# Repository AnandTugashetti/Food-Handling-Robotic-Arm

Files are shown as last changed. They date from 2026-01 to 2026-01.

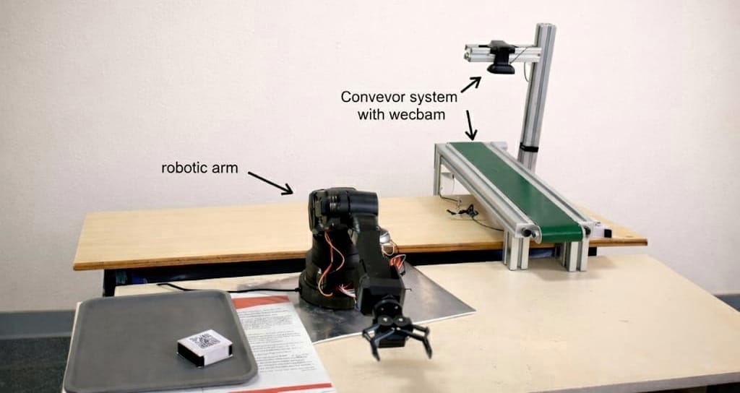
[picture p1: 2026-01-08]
Full_setup_Model.jpeg

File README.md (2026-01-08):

🍽️ Food Handling Robotic Arm

An automated robotic system designed to handle packed food items safely and efficiently using a robotic arm, conveyor belt, and QR-code–based identification.

📌 Project Overview

The Food Handling Robotic Arm project aims to improve hygiene, accuracy, and speed in food handling by reducing human involvement. The system uses a robotic arm integrated with a conveyor belt and a camera-based QR scanning mechanism to automatically pick, sort, and place packed food items to their respective destinations.

This solution is suitable for small to medium-scale food industries and Quick Service Restaurants (QSRs) where fast and reliable order handling is essential.

⚙️ System Features

Automated pick-and-place operation

QR code–based food package identification

Conveyor belt coordination

Servo motor–controlled robotic arm

Minimal human intervention

Modular and scalable design

🧠 System Workflow

Food package moves on the conveyor belt

Webcam scans the QR code on the package

Order or customer information is decoded

Decision is made for destination placement

Robotic arm picks the package

Package is placed at the assigned location

🧾 Project Report

File: Food_Handling_Robotic_Arm_Report.pdf

Contents Include:

Introduction and objectives

Literature survey

System design and development

Hardware and software implementation

Testing, results, and discussion

Conclusion and future scope

🧩 Autodesk Fusion 360 – Robotic Arm Design

File Name: Food_Handling_Roboticarm_Design

Software Used: Autodesk Fusion 360

The robotic arm used in this project was designed and modeled using Autodesk Fusion 360. The software was selected for its powerful parametric modeling tools, easy assembly management, and accurate visualization capabilities, which are well suited for robotic system design.

The complete robotic arm design includes:

Base structure

Shoulder, elbow, and wrist joints

End-effector (mechanical gripper)

Servo motor mounting brackets

Linkages and joint connections

Each component was modeled individually and then assembled to ensure proper alignment, range of motion, and mechanical stability. Joint constraints and motion limits were applied to simulate real-world arm movements and to verify reachability and workspace.

🌐 Roboslice – Food Ordering Web Application

Application Name: Roboslice

Live Link: https://roboslice.onrender.com/

Type: Web-based food ordering system

Roboslice is a web application developed to manage food orders digitally and integrate seamlessly with the automated food handling system. It allows customers to place orders easily and generates a unique QR code for each order, which is later used by the robotic arm system for identification and sorting.

📝 Order Creation Process

Using the Roboslice web application, the user can place an order by providing the following details:

Food item selection

Customer name

Quantity of items

Order type (Dine-in or Takeaway)

Payment confirmation

Once all required inputs are submitted, the system automatically generates a unique QR code for the order.

🔲 QR Code Generation

Each order is assigned a unique QR code

The QR code contains essential order and customer information

This QR code is printed or attached to the food package or bill

The generated QR code is later scanned by the webcam-based QR scanner

This QR code acts as a digital link between the web application and the robotic arm system, enabling automated decision-making.

🔗 Integration with Robotic Arm System

The webcam scanner reads the QR code generated by Roboslice

Order data is decoded and processed

The system identifies the correct customer or destination

The robotic arm performs accurate pick-and-place operations

This integration ensures faster order handling, reduced errors, and minimal human involvement.

🤖 Robotic Arm Control Code

Folder: Robotic_arm_arduino_code

Software Required: Arduino IDE

Purpose:
Controls servo motors, robotic arm movement, and pick-and-place operations.

▶️ How to Run

Open Arduino IDE

Open the .ino file from : Robotic_arm_arduino_code

Select the correct Board and COM Port

Upload the code to the Arduino

📷 Webcam QR Scanner Code

Folder: webcam_scanner_code

Software Required: Visual Studio Code (VS Code)

Purpose:
Scans QR codes using a webcam to identify orders and trigger customer-related actions.

▶️ How to Run

Open VS Code

Open the : webcam_scanner_code folder

Install required Python libraries:

pip install opencv-python pyzbar

Run the scanner script

🧪 Testing Summary
End-to-end automation successfully demonstrated

Reliable QR detection under proper lighting

Effective handling of 150–300 g food packets

Average cycle time: ~30 seconds per order

🚀 Future Enhancements

Adaptive or soft robotic grippers

Vision-based alignment correction

IoT integration for order tracking

Cloud-based monitoring and analytics

Industry 4.0–ready automation

📜 License

This project is intended for academic and educational use.

Feel free to fork, modify, and improve the system.

👤 Author

Anand Tugashetti

Robotics & Automation

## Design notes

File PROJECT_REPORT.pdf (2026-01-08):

A PROJECT REPORT ON

## FOOD HANDLING ROBOTIC ARM

ANAND TUGASHETTI
2025-2026

ABSTRACT

Automation tends to become a key enabler in modern food industries, enhancing hygiene,

efficiency, and accuracy while reducing dependence on manpower. Challenges faced in

conventional food handling practices include contamination risks, inconsistent handling

quality, slower processing speed, and higher labour costs. The main goal of this project is thus

to design and develop a Food Handling Robotic Arm, an automated system that would safely

and efficiently handle packed food items with minimal human involvement.

The fundamental idea of the project is to design an automated mechanism which can pick,

place, and sort packed food items arriving from a kitchen and deliver them to the correct

customer or the respective section. The robotic arm-based system with a conveyor belt, camera-

based identification, sensors, servo motors, and a microcontroller-based control unit provides

a complete automated solution. A food package traveling on the conveyor may have a QR code

or barcode printed on the package or order bill, which is detected and scanned by a camera.

The scanned data is processed through a microcontroller that decides to which destination it

should go based on the information regarding customers or delivery. Based on this decision,

the robotic arm executes a pick-and-place operation with high precision.

It works on the principle of continuity and repetition. Once a package is detected, the robotic

arm is guided to the pickup point, where a soft, food-grade gripper gently grips the package to

avoid damage. The arm then transfers and places the item accurately at the assigned location.

This operation will be looped so that the system can handle multiple orders of food efficiently

with high speed and reliability.

The advantages of the Food Handling Robotic Arm include better hygiene with less human

contact, consistent accuracy of handling, and speedier ways of processing orders. Its design is

modular and adaptable, fitting into small kitchens and large-scale food industries. This system

shall be very useful in QSRs like Domino's, Burger King, McDonald's, and KFC since these

need quicker service due to high order volumes. Overall, the project showcases a highly

feasible automation solution aimed at enhancing operational efficiency, hygiene, and customer

satisfaction, while also opening up future possibilities of IoT and Industry 4.0 integration.

TABLE OF CONTENTS

2.28 Design and Control of Soft-Rigid Grippers for Food Handling | 29
2.29 Review of Robotic Grippers for High-Speed Handling of Fragile Foods | 29

2.30 Design and Field Evaluation of End Effector for Robotic Strawberry Harvesting...30

Chapter 3: Problem Statement | 32
Chapter 4: Objectives | 33
Chapter 5: Design & Development | 34
5.1 Overview | 34
5.2 System Design & Mechanical Design | 35
5.3 Development Framework for the Robotic Food Handling System... | 37
5.4 Workflow Diagram of Automated Food Handling System | 38
Chapter 6: Implementation | 39
6.1 Hardware Implementation | 40
6.2 Software Implementation | 48
6.3 Servo Motor Control Connections | 40
6.4 Roboslice – Web Application | 50
Chapter 7: Validation & Testing | 52
7.1 Validation Objectives | 52
7.2 Testing Setup | 53
7.3 Full System Integration Testing | 54
Chapter 8: Results & Discussion | 57
Conclusion | 59
Future Scope | 60
References | 61
Plagiarism check report | 63

LIST OF TABLE

Sl.No | Description | Page No.
Table 7.1 | End-to-End Cycle Success Rate | 55

LIST OF FIGURES

Sl.No | Description | Page No.
Fig 5.1 | Block Diagram | 34
Fig 5.2 | Workflow Diagram | 39
Fig 6.1 | Circuit Diagram | 40
Fig 6.2 | Arduino Uno | 41
Fig 6.3 | MG995 Servo Motor | 42
Fig 6.4 | SG90 Servo Motor | 43
Fig 6.5 | Conveyor System | 43
Fig 6.6 | Webcam | 44
Fig 6.7 | Lithium Battery | 45
Fig 6.8 | 3D Printing Filament | 46
Fig 6.9 | Breadboard | 46
Fig 6.10 | Adapter | 47
Fig 6.11 | Jumper Wires | 47
Fig 6.12 | Geared DC Motor | 48
Fig 6.13 | 3D Model of Robotic Arm | 49
Fig 7.1 | Robotic Arm | 55
Fig 7.2 | Mechanical Gripper | 55
Fig 7.3 | Conveyor | 55
Fig 7.4 | Robotic Arm Components | 55
Fig 7.5 | Testing Of Robotic Arm | 56
Fig 8.1 | Complete Working Model | 58

## CHAPTER 1

## INTRODUCTION

With kitchens getting smarter and food moving quicker, the quiet revolution shaping their

future is not culinary, but robotic. The rapid growth of automation during the 21st century has

evidently restructured industries across the world and considerably influenced how products

are created, processed, packed, and delivered. Of all sectors undergoing transformation, the

food industry stands out as one of the most demanding, complex, and sensitive domains to

integrate technology. Food is not just another commodity-it is essential for life and hence

requires handling with high standards of hygiene, precision, safety, and efficiency.

### 1.1 Introduction to Robotic Automation in Modern Food Handling

In recent years, the rise of quick-service restaurants, cloud kitchens, large commercial food

outlets, and online delivery platforms worldwide has amplified the challenge of managing huge

volumes of food items with speed and accuracy. Given this backdrop, robotic automation is

emerging as a promise that can handle not only operational inefficiency but also hygiene-

related issues. The development of a food-handling robotic arm addresses these growing

industrial needs and thus presents a pathway to enhancing efficiency, improving safety, and

raising the overall standard for performing food handling.

The modern food consumer expects speedy delivery, accuracy, and safety. When ordering

through an online platform or dining in-store, delays, mistakes, or unsafe handling will badly

affect customer confidence. Traditional food-handling environments rely heavily on human

labor. While humans are endowed with dexterity, adaptability, and decision-making ability,

they are also susceptible to fatigue, inconsistency, errors, and limitations during peak demand

periods. In a busy kitchen or zone of food dispatch, workers tend to perform repetitive tasks

like sorting packaged meals, checking order labels, routing trays to different sections, and

organizing prepared plates for serving or dispatch. These simple-appearing tasks require

uninterrupted concentration and physical stamina. Over some time, the monotony of such tasks

leads to degraded accuracy, slower performance, and bottlenecks in operation. Further, direct

human contact in handling food increases the chances of contamination, highlighted throughout

the COVID-19 pandemic.

Automation presents an alternative to this system because it guarantees precision, consistency,

and operation without interruption. A food-handling robotic arm designed for executing repetitive tasks at very high speeds with high accuracy can operate around the clock and

drastically minimize the chances of cross-contamination. Equipping it further with an

intelligent system such as barcode or QR-code scanning allows the direct identification,

sorting, and routing of packaged items automatically without human oversight. So instead of

reading labels, workers could take advantage of the robot's interpretation of data instantly and

move items to their allocated places. This combination of robotics and machine perception

transforms the work from labor- to data-driven with exceptional efficiency.

### 1.2 Challenges, Technological Enhancements, and Industrial Relevance

The idea of using robotic arms in industry is not new; the so-called robotic manipulators have

been in use in manufacturing, automotive assembly, pharmaceuticals, and production of

electronics. However, the food industry presents some unique challenges that significantly

differ from the requirements of traditional industrial automation. Foodstuffs differ in shape,

texture, and fragility, along with several different packaging styles. While a metal component

on an assembly line may not be affected when handled with firm gripping or fast-moving

motions, a packaged food item or a soft edible product might deform, create spills, or otherwise

be damaged if subjected to excessive force or an incorrectly designed gripping mechanism.

This, however, has fueled the development of food-safe gripping technologies, including soft

robotic grippers, vacuum-based grippers, and an adaptive mechanism capable of modifying

grip pressure depending on the character of an object. Such advances now make it possible for

robotic arms to handle delicate or irregularly-shaped food items with high-quality manipulation

close to that of human hands.

Apart from gripping technology, the integration of machine vision is what allows robotic arms

to intelligently interact with the environment in which they exist. QR codes and barcodes are

now universal ways of embedding information regarding order numbers, customer IDs,

packing timestamps, temperature, and routing information. This information, through camera-

based scanning systems, can be decoded in real-time as a robotic arm views it and carries out

decisions on placement and sorting. This removes dependency on manual verification and

reduces logistical errors. When integrated into conveyor systems or modular food dispatch

environments, such robotics technology creates a seamless flow where each food item moves

through a digital pipeline from preparation to dispatch.

The need for such automation has been further intensified due to the changing structure of food

distribution systems. Cloud kitchens—places specifically dedicated to preparing online food

orders without dine-in facilities—are enjoying increasing popularity, meaning the number of orders daily could be very high. Cloud kitchens rely heavily on optimized workflows to

maintain profitability. A single delay in sorting or routing food containers can create order

bottlenecks, extend delivery times, and reduce efficiency. As multiple brands operate under

one kitchen roof, simultaneous orders become all the more complex to handle. Robotic arms

are capable of performing such tasks in large volumes with consistency and accuracy, thus

providing a standardized solution to these challenges. They can manage everything, from

picking boxed meals from a conveyor and scanning their QR labels to depositing them into

assigned racks for delivery partners, without fatigue or error.

Beyond efficiency and hygiene, robotic automation supports broader industrial goals in line

with the principles of Industry 4.0. This new wave of industrial transformation emphasizes

interconnected systems, data-driven decision-making, real-time monitoring, and intelligent

automation. A food-handling robotic arm can be easily integrated with IoT devices, kitchen

management software, cloud-based analytics, and automated dispatch systems. Every food

packet handled by the robot can be digitally logged, making traceability transparent and

accurate. Processing times can be monitored, the busiest hours can be identified, workflow

bottlenecks can be predicted, and staffing can be optimized based on data insights. Because the

robotic system records every movement, it provides unprecedented visibility into the food-

handling pipeline, offering opportunities for continuous improvement.

Furthermore, advances in technology have made robotic systems more available and

affordable. While previously robotic automation was made possible only in large factories with

big budgets, today it has become accessible to even small- and medium-scale food businesses

due to modular actuators, low-cost microcontrollers, 3D-printed parts, and opensource robotic

frameworks. Today, a multi-degree-of-freedom robotic arm can be realized at a fraction of its

earlier cost while maintaining high reliability. The integration of opensource libraries for QR-

code recognition, microcontroller-based control systems, and low-cost camera modules will

make the technology practical and scalable. As robotics becomes more affordable, its potential

to revolutionize the food industry expands further.

In view of these considerations, the development of a food-handling robotic arm is not an

academic exercise; it is to find a solution for practical industrial problems. This project tries to

fill the gap between practical kitchen operations and future automatic food handling. Hence, it

handles some major challenges like sorting errors, hygiene risks, labor shortcomings, and

inefficiency in operations. Combining robotic manipulation with computer vision, the system

shows how technology can improve quality and speed in food handling.

## CHAPTER 2

## LITERATURE SURVEY

The literature survey reviews the existing research on robotic automation in food handling,

including discussions related to pick-and-place systems, vision-based identification, conveyor-

integrated robots, and food-safe gripper designs. Previous work underlines the role of robotic

arms in enhancing hygiene, accuracy, and efficiency in food processing applications. The

survey also identifies the need for integrated, cost-effective solutions combining sensing,

control, and automation specifically for modern food handling applications.

### 2.1 Robotic Manipulation of Food Products

Author: P.Y. Chua, T. Ilschner, D.G. Caldwell

This paper provides in-depth discussion on the advances, challenges, and opportunities of

applying robotic systems to food handling and processing. Although the food industry is among

the largest manufacturing sectors in the world, its automation is lagging behind the automotive

and electronic industries. This is mostly because food products are variable, soft, and easily

deformed, hence difficult to handle by conventional robotic manipulators. The authors stressed

that automation in this sector is very important for enhancing hygiene, efficiency, and

profitability without compromising on strict food safety regulations.

The paper identifies the core problems of robotic food manipulation in terms of product size

and texture variations, which are easily deformed or contaminated, and which require a truly

cleanable robot. Three of the major strategies for gripping are discussed in more detail.

Mechanical grippers achieve their hold through friction or clamping and can be used on

products like meat or fish. Fragile produce is at risk with this type of gripper. Intrusive grippers

pierce through a material and cannot be considered due to hygiene implications. Surface

attraction grippers, which involve suction, adhesives, or electrostatic forces, offer greater

adaptability but tend to get clogged or contaminated easily. New approaches involve ideas like

freezing grippers by using rapid ice adhesion and airflow-based noncontact grippers.

The authors illustrate several practical robotic applications, including food processing and

manufacture. Washable manipulators execute cutting and dressing operations in meat

processing with high accuracies and hygiene standards. The grippers of poultry-handling robots

use pneumatic muscles to avoid damages on their fragile tissues. SCARA robots automatically

de-head fish on the "RoboFish" project, while sensors and pneumatics enable the robotic milking systems to milk cows accurately and independently. Agricultural robots execute

selective harvesting on asparagus, fruits, and mushrooms where vision systems and soft

grippers are integrated into the robotic apparatus. Automation of packaging, examples include

ABB's FlexPicker and Intelligent Integrated Belt Manipulator, presents the most successful

area of food robotics due to standardized material and shape inputs.

### 2.2 Kinematic Modelling & Maneuvering of 5-Axes Articulated Robot Arm

Author : T.C. Manjunath

This paper presents the complete design, mathematical modeling, simulation, and real-world

implementation of a 5-DOF articulated robotic arm developed totally from indigenous

components. The paper focuses on the derivation of an accurate direct kinematic model for the

manipulator using the D–H convention and further validates the model through simulation and

actual pick-and-place experiments. The robot has five rotary joints (base, shoulder, elbow,

pitch, and roll), and is designed as an educational platform for teaching robotic manipulation.

It is powered by DC servomotors through gear–chain transmission systems and incremental

encoders with a resolution of 0.624° per count at the load shaft. The manipulator is therefore

able to execute high-precision joint motions. The D–H based modeling process involves the

assignment of six coordinate frames, the derivation of 20 kinematic parameters, and the

computation of the sequence of homogeneous transformation matrices from the base to the

tool-tip. These matrices are partitioned at the wrist to simplify computation, thereby allowing

the computation of end-effector position and orientation relative to the base. One complete

composite transformation matrix T₅⁰ is formulated and validated by substituting the soft-home

joint angles of the robot.

The author then develops a detailed link coordinate diagram or LCD, computes joint variables,

link lengths, offsets, and twist angles, and constructs a full kinematic parameter table. The

correctness of the derived matrices is verified by evaluating the transformation matrices at the

home position and cross-checking with the LCD.

A C++-based GUI is developed to realize real-time simulation and control of the robot.

MATLAB simulations performed show consistency with the experimental results in pursuing

accurate trajectory tracking and successful autonomous pick-and-place manipulation.

Concluding, the paper develops a comprehensive kinematic approach and its practical

implementation for a 5-axis robotic arm, with a particular emphasis on its application as an

affordable platform for teaching robot kinematics and manipulation in educational and research

settings.

### 2.3 Low-Cost Compliant 7-DOF Robotic Manipulator

Author : Morgan Quigley, Alan Asbeck, and Andrew Y. Ng

The paper presents the design and implementation of an affordable, human-safe robotic arm

that is intended for manipulation research. Unlike the commercial manipulators that often

exceed $100,000, this system achieves backlash-free actuation, sub-3 mm repeatability, 1.5

m/s speed, and a 2 kg payload at the low parts cost of $4135. The motivation behind this project

was to accelerate robotics research by making high-performance arms financially accessible,

enabling their wider adoption in labs, classrooms, and small-scale industries.

The key innovation of the arm is its hybrid actuation mechanism. The proximal four joints

utilize stepper motors with timing belts and cable drives, providing features like high torque,

zero backlash, and intrinsic mechanical compliance. This series-elastic design increases human

safety because external forces applied to the arm cause it to safely deflect. The distal three

joints employ Dynamixel RX-64 servos that enable higher bandwidth motion while allowing

overall flexibility.

Low-cost manufacturing is achieved with laser-cut plywood and off-the-shelf components,

with no expensive machining. The compliance mechanism makes use of polyurethane tubes

deforming under force; thus, accurate force sensing is achieved through encoder measurements.

Equipped with the full sensing stack—optical encoders, motor step tracking, and ROS-based

software integration—the arm features closed-loop control, inverse kinematics, and Cartesian

motion planning.

Performance tests demonstrate excellent repeatability and payload handling, whereas

demonstration tasks such as teleoperated chess-playing and pancake-making highlight the

arm's capability for fine manipulation and safe human interaction.

The authors conclude that this low-cost, compliant 7-DOF arm represents an important step

toward affordable, safe manipulation systems. Future work will involve simplifying

fabrication, improving force sensing, and moving toward more durable metal structures to

make compliant robots practical for widespread deployment.

### 2.4 Unified Closed Form Inverse Kinematics for the KUKA YouBot

Author : Shashank Sharma, Gerhard K. Kraetzschmar, Christian Scheurer, and Rainer

Bischoff

This paper proposes a new analytical inverse kinematics solution for the KUKA youBot mobile

manipulator by considering it as a unified 8-DOF serial kinematic chain, where the base and

5-DOF arm are included. The authors fill a key gap in the literature on mobile manipulation:

although mobile platforms introduce redundancy that should enhance reachability and

flexibility, most systems operate the base independently of the arm and rely on heuristic-based

planning. In this paper, the authors propose a unified closed-form IK solver able to

systematically exploit redundancy, thus enabling more efficient and deterministic manipulation

in complex environments.

The paper initiates by explaining the difficulties of mobile manipulation, especially the

coordination of base motion and arm articulation for accomplishing 6D end-effector goals.

Since the youBot's arm has only 5 degrees of freedom, the missing DOF must be compensated

by platform movement. The authors introduce three redundancy parameters (ρ1, ρ2, ρ3): ρ1

resolves rotational redundancy between base and first joint, ρ2 adjusts linear redundancy linked

to arm reach, and ρ3 determines elbow configuration (up or down).

A systematic, analytical IK framework is developed. The solver first extracts orientation

parameters β and θ from the Cartesian goal pose and then computes the arm joint angles (θ2,

θ3, θ4), based on geometrical and trigonometric relationships. In order to satisfy the overall 6D

goal pose, the position (x, y) of the mobile base and the orientation will be derived, while θ5 is

computed from the rotational alignment between the current and desired end-effector frames.

The valid range of redundancy for the solver is also defined based on mechanical constraints.

Simulation and experimental results demonstrate smooth joint trajectories for redundancy

parameter updates confirming independence and allowing true nullspace motion. The unified

solver enables efficient manipulation planning using IKBiRRT without heuristic base

sampling.

They conclude that this unified closed-form IK solution significantly advances mobile

manipulation since it allows the youBot to fully exploit its redundancy and perform more

robustly and efficiently in complex tasks.

### 2.5 An Evaluation System of Robotic End-Effectors for Food Handling

Author: Zhe Qiu, Hannibal Paul, Zhongkui Wang, Shinichi Hirai, Sadao Kawamura.

The paper presents a holistic framework for the assessment of robotic end-effectors in

performing manipulation tasks related to food handling. The motivation has come from

growing demands on automation within Japan's food industries, which have been driven by

labor shortages and the complexity of handling a wide variety of food stuffs. Most of the

already-developed robotic end-effectors are designed for specific types of food; hence, their

generalization is limited. In this work, an attempt has been made to propose an evaluation

system that can quantitatively and graphically visualize the performances of various end-effectors in manipulating different food materials, with the objective of aiding in the selection

or new design of end-effectors.

The authors classify the food items and the robotic end-effectors according to their physical

and functional characteristics. Food products are categorized according to such body properties

as shape, size, weight, elasticity, and fragility, while surface properties include friction,

stickiness, humidity, and temperature. These parameters directly affect the grasping success

and product safety. On the other hand, robotic end-effectors are classified according to their

contact position during handling in top, side, and bottom configurations-in other words, T-type,

S-type, B-type, or hybrid configurations, like TS, BS, and TBS types. Such a classification

enables structured performance comparisons among several device designs. The evaluation

framework consists of a robotic system based on the ROS 2 platform, equipped with a Denso

robotic arm, pneumatic controllers, and an Intel RealSense 3D camera for visual recognition.

The methodology included standardized pick-and-place experiments on 14 different food items

using seven soft robotic end-effectors. Each end-effector's adaptability is rated across seven

properties: shape, size, weight, friction, elasticity, stickiness, and fragility. Performance scores

are visualized using radar charts, which provide an intuitive representation of overall efficiency

and capability.

Experimental results indicated that no single end-effector operates optimally for all types of

food. For example, suction-based grippers operate well on smooth surfaces but failed when the

item was sticky or had a coarse surface. Pneumatic and soft-finger grippers displayed greater

adaptability, especially when it came to fragile or oddly-shaped foods. Radar-based

visualization of scoring offered insight into design limitations and provided direction for end-

effector optimization.

### 2.6 Vision Assisted Pick and Place Robotic Arm

Author : Nisha, Dinesh Kumar, Sekar, and Indira

The paper describes the design and implementation of a 2-DOF robotic arm integrated with a

machine vision system that is capable of fully automated pick-and-place operations. This

system differs from traditional manually guided robotic arms in such a way that it utilizes a

USB camera as a vision sensor and incorporates LabVIEW Machine Vision (NI-IMAQ) for

capturing live images and processing. The primary objective remains to identify an object

autonomously, measure its dimensions, and precisely guide the robot to pick and relocate it

without human interference.

The robotic arm is fabricated from lightweight acrylic sheets and actuated by three servo

motors: one each for the base, wrist, and gripper. The base rotates the entire arm, the wrist

provides vertical motion, and the gripper, through a servo-driven wheel mechanism, is able to

grasp widths from 1.0 to 9.3 cm. It has a total mass of 500 g and is 19 cm tall, and therefore is

cost-effective, portable, and suitable for small-scale automation.

The vision system captures object images and performs image processing based on RGB-to-

grayscale conversion, pattern matching, and edge detection algorithms. Pattern matching finds

template similarity and extracts pixel coordinates while edge detection, with the Prewitt

operator, computes the dimensions of objects. Pixel values are converted to real-world units

using a calibration constant 1 pixel = 0.026458 cm. These measurements are then sent to the

servo motors via RS-232 communication using an LPC2129 ARM7 microcontroller

programmed to produce the appropriate PWM signal that drives the servos.

Experimental tests demonstrate the system reliably detects object dimensions, while slight

discrepancies exist due to camera resolution and other illumination factors. The authors identify

that the integration of vision significantly improves the automation capability, but full-scale

industrial applications will involve increasing DOF up to at least seven and employing higher-

resolution 3D cameras in order to achieve more accurate sensing.

### 2.7 Design and Implementation of Pick and Place Robotic Arm

Author : Ravikumar Mourya, Amit Shelke, Sourabh Satpute, Sushant Kakade, Manoj Botre

The paper describes the complete mechanical, control, and analytical development of a 4-DOF

articulated pick-and-place robotic arm for cylindrical objects weighing up to 150 grams. The

objective of the study was to replace human intervention in repetitive material-handling tasks

and to present a lightweight, low-cost, and efficient robotic solution for industrial

environments.

The authors first present the necessity for robotic manipulators and emphasize their role in

hazardous, repetitive, or precision-demanding tasks. The robotic arm described here uses a

model based on the human upper limb, having four revolute joints with each joint actuated by

a servo motor. This, in turn, provides four degrees of freedom: shoulder rotation, elbow

rotation, wrist rotation, and gripper rotation. Control is achieved through an ATmega16

microcontroller and a serial servo controller, enabling smooth motion and coordinated axis

operation.

The selection of material was one of the important design considerations. Lightweight

aluminum and rectangular sheet sections will provide rigidity and stability by reducing load on

the base and shoulder. This gripper is designed to securely grasp a cylindrical object up to a

volume of 150 ml and weighing up to 150 g. A CAD model for the arm on Creo should be

created, including a complete 3D assembly of the base, shoulder, elbow, wrist, and two-

fingered gripper.

A detailed inverse kinematics analysis, using RoboAnalyzer, calculates joint angles for a

number of target positions that confirm the reachable workspace and the allowable trajectories.

Joint value, velocity, acceleration, and torque graphs confirm smooth dynamic behavior.

The authors perform FEA on major components like the shoulder base, elbow, and fingers

using ANSYS to ensure that structural integrity is maintained. Stress and deformation plots

also show all parts operate well within safe limits under expected loads.

The paper concludes by successfully demonstrating the design, simulation, and analysis of a

functional 4-DOF robotic arm that can perform pick-and-place operations reliably. According

to the authors, the system provides a practical and cost-effective solution for industrial

automation, and its performances can be further improved with better control algorithms and

sensor integration.

### 2.8 Design and Construction of a Robotic Arm

Author: Md. Tasnim Rana & Anupom Roy

The paper outlines the design of an affordable, efficient robotic arm for industrial applications.

The authors designed a programmable mechanical arm that emulates the structure and

movement of the human arm for performing precise, repetitive, and hazardous tasks in industry.

The aim was to develop a low-cost autonomous robotic system that can execute fundamental

operations like object detection, gripping, and placement using basic electronic and mechanical

elements. The authors highlight how robot arms are already applied in assembly lines for tasks

such as welding, material transfer, and packaging, and how similar designs can be adapted for

rescue or hazardous operations like bomb disposal and firefighting.

The proposed system has two major subsystems: the mechanical assembly and the signal

processing unit. The mechanical system consists of a servo and stepper motor that emulates

human arm joints, which are capable of both rotational and translational motion. The signal

processing part is based on an Arduino Uno R3 microcontroller. Sensors like an ultrasonic sonar (HC-SR04) are integrated which detect the position of objects, thus enabling the arm to

scan its surroundings and identify different objects and compute their coordinates. A

mechanical gripper or claw serves as the end-effector, capable of securely holding objects up

to 55mm in width. The power supply of the arm is a 9V DC with the option for solar recharging,

enhancing its sustainability. This methodology involves a step-by-step motion control

sequence: scanning, object detection, grasping, transport, and reset. For joint actuation, this

prototype uses four servos and one stepper motor to achieve base rotation for a 360° workspace.

MATLAB visualization software helps in simulating the trajectory taken by the arm and its

workspace in three dimensions.

Experimentally, the robotic arm is able to illustrate fine motion control and object manipulation

based on minimum power consumption. It offers four degrees of freedom and adopt modular

structural elements, balancing functionality and affordability. The limited travel range of the

servos diminishes the comparison with more expensive industrial robots; however, due to the

simplicity and reliability, the educational, small-scale industrial, and laboratory employment

of the manipulator is very suitable.

2.9 A Review of Robotics and Autonomous Systems in the Food Industry.

Author: Linh N.K. Duong, Mohammed Al-Fadhli, Sandeep Jagtap.

The authors conducted a systematic literature review of 54 research papers using a structured

nine-step procedure. They found five major themes that define the impact of RAS in food

supply chains, namely food quality, food safety, food waste management, supply chain

efficiency, and supply chain analysis. Each theme underlines the potential of robotics and

automation in adding value to different dimensions of the agri-food ecosystem.

They also note that food quality is increasingly monitored along the supply chain for freshness,

color, texture, and temperature using computer vision, multispectral imaging, and IoT-based

systems. These ensure real-time quality control with minimal human inspection. Applications

related to food safety make use of traceability systems like RFID, blockchain, and wireless

sensor networks to monitor handling conditions and prevent contamination. Walmart enhances

food traceability by using RFID in China, from farm to consumer, enabling enhanced

transparency and accountability.

The paper further illustrates that RAS allows for real-time tracking of waste and predictive

analytics to reduce overproduction and spoilage. Systems integrated with IoT at the processing

plants can monitor inefficiencies, and AI-based forecasting tools at restaurants help optimize

production and minimize waste. Automation in logistics, inventory control, and agricultural

operations by making use of drones, autonomous vehicles, and intelligent warehousing systems

improves efficiency in the supply chain. This lowers energy usage and dependence on labor

while assuring consistent operations. Supply chain analytics with the power of big data and

machine learning enables decision-making and sustainability assessments across global

networks.

### 2.10 Robot Arm Control with Arduino

Author : Aimn Mohamed Ahmed Ghiet and Dr. Abdellatif Baba

The following report describes in detail the design, development, and implementation of a 4-

axis robotic arm. Control of this robotic arm is by an Arduino Nano using a Bluetooth-based

Android application. The work integrates mechanical design, microcontroller programming,

servo motor actuation, and wireless communication to realize an affordable, functional robotic

arm capable of user-defined movements like lifting, carrying, mixing, and repeating stored

motion sequences.

The project starts by explaining the theoretical basics, above all the role of servo motors, which

are chosen because of their accuracy, high torque, and easy control via PWM signals. Five

TowerPro SG90 mini servo motors actuate the four axes plus gripper, allowing to perform

different movements like rotation, lifting, bending of the elbow, wrist action, and gripping. The

authors also provide a description of the Arduino Nano microcontroller, chosen for simplicity,

open-source support, and its rich library ecosystem, which makes it fit both for beginners and

advanced users.

It features a Bluetooth HC-06 module for wireless communication between the robot arm and

an Android app designed with MIT App Inventor. The user can manually adjust each axis using

“+” and “–” buttons, send commands, save positions into EEPROM, and replay recorded

sequences for the robot to perform repetitive tasks autonomously.

The arm is designed mechanically using SolidWorks, while the components are fabricated

using lightweight materials, including 3D-printed parts. A detailed explanation of the

kinematics of the robot arm, which covers Denavit–Hartenberg parameters, forward and

inverse kinematics, and transformation matrices, provides a mathematical basis for understanding robot motion. Experimental results confirm smooth and precise motion along all

axes. The system performs pick-and-place tasks reliably, and a number of real advantages of

integrating mechanical engineering with electronics and embedded programming have been

illustrated. The authors conclude that Arduino-based robotic arms are scalable, low-cost, and

suitable for educational, medical, and industrial automation applications.

### 2.11 Design of 6-Axis Robotic Arm

Author : Abhishek Bhambere

The paper presents the complete mechanical design, selection of materials, torque analysis, and

simulation-based validation of a stationary 6-axis robotic arm meant for pick-and-place

applications. The focus of the work is to develop a cost-efficient yet structurally robust

manipulator that can achieve human-arm-like motion through pitching, rolling, and yawing

degrees of freedom. The main design constraints in this work include a nominal payload of 0.5

kg, horizontal reach of 0.6 m, and accuracy of 3 mm to ensure practical use in manufacturing,

handling of electronics, and assembly lines when human intervention is restricted.

The selection of structural materials starts the study. Plain carbon steel 45C8 is selected for

brackets, shafts, and plates since it offers a very good strength-to-cost ratio, is machinable, and

weldable. For flexible components, like flanges, Aluminium 6082-T6 is used. Belt drives will

be done using PET rubber and plastic pulleys. A detailed CAD model has been developed on

SolidWorks and imported in V-REP to simulate the torque requirement and feasibility of the

motions. Inverse kinematics and joint force modules of V-REP enabled the accurate calculation

of the required torques in all the six axes, which are in the tune of 16.55 N-m (Axis-1) to 0.049

N-m (Axis-6). After simulation, manual torque calculations are made using classical formulae,

T = F × r, whereby each joint's load comprises the mass of motors, belts, pulleys, links, and the

gripper. The paper also features lengthy pulley-belt selection tables, determining gear-

reduction ratios necessary to minimize motor cost while providing adequate output torque.

Shaft diameters are calculated from equations involving bending and torsional stress, using

safety factors that ensure structural reliability. Bearings are selected by making use of SKF

dynamic load ratings depending on expected revolutions and load factors.

The final results confirm that the design meets all the payload and accuracy requirements with

a factor of safety of 1.5, allowing the arm to lift up to 0.7 kg without modification.

### 2.12 Challenges for Industrial Robot Applications in Food Manufacturing

Author : Farah Bader and Shahin Rahimifard

This paper looks at the gradual but steadily growing application of IRs within the food

processing industry and compares it with the rapid automation attained so far in the automobile

and electronics industries. Also, in spite of the long-recognized advantages of efficiency,

precision, and flexibility of industrial robots, the food industry still depends mostly on manual

labor because of the fragile, variable, and perishable nature of food products, along with high

hygiene and safety requirements. The paper therefore gives a broad overview of the rationale,

applications, challenges, and future outlook of robotics in manufacturing foodstuffs and

positions automation as quite vital for meeting the global increase in demand.

According to the authors, major drivers accelerating automation include: changing consumer

expectations for customized and sustainable products, strict government regulations on

traceability and hygiene, a shortage of labor due to geopolitical changes like Brexit, and an

increased need of manufacturers for efficiency and competitiveness. Such pressures push the

sector toward flexible, reconfigurable production systems. Industrial robots are automatically

controlled, reprogrammable, multi-purpose manipulators. According to ISO, they have the

advantage of speed, precision, repeatability, and adaptability. Examples include ABB's IRB

360 FlexPicker achieving up to 200 picks per minute and KUKA robots functioning effectively

in sub-zero conditions.

Despite these advantages, the study identifies four key barriers to wide-scale diffusion: difficult

handling of fragile and variable food items; stringent hygiene and wash-down requirements;

economic and social issues including high perceived costs and job displacement fears; and skill

shortages due to limited cross-disciplinary expertise. This paper concludes by stating that

industrial robots would lie at the heart of future food systems that conform to Industry 4.0.

Advanced soft robotics, sensor integration, and AI-based controls are bound to drive the global

food robotics market past £2.7 billion in a shift toward intelligent, hygienic, and fully

automated ecosystems in food manufacturing.

### 2.13 Pose Estimation and Bin Picking for Deformable Products

Author : Benjamin Joffe, Tevon Walker, Remi Gourdon, Konrad Ahlin

This paper presents a deep learning-based robotic system for handling deformable food

products, such as poultry, through pose estimation and automated bin picking. The authors introduce an integrated robotic system able to detect, pick, and reorient unordered bins of

deformable poultry products into a consistent "canonical pose" that enables further automation

in downstream tasks.

Advanced computer vision is combined with machine learning in the system. A UR-5 robotic

arm fitted with a suction cup gripper and an Intel RealSense D435 RGB-D camera is employed.

A Faster R-CNN neural network uses a ResNet-101 feature extractor to perceive and locate

objects against cluttered bins. These object centroids are then transformed into 3D coordinates

and fed into the robotic controller for planning grasping points. The gripper is designed to

achieve a vacuum seal on relatively flat surfaces, ensuring the soft and slippery chicken

surfaces are handled without causing any deformation or damage.

The authors develop and compare two methods for pose estimation: a direct quaternion

regression model and an augmented auto encoder architecture. Both estimate the 6D pose of

the poultry in terms of three translational and three rotational parameters. A regression model

directly outputs the quaternion-based rotations, whereas the augmented auto encoder implicitly

reconstructs the object orientations from synthetic image data. The auto encoder model showed

better generalization with more robust performance under variable lighting and shape

conditions. Synthetic training datasets with random augmentations (such as scaling, color

jittering, and background noise) increased robustness against environmental variability.

Experimental results showed a 92% success rate for bin picking and an 81% success rate for

canonical pose placement with the augmented autoencoder model, whereas the best performing

regression method achieved a success rate of only 32%. The experimental results also indicated

that temperature changes affected skin stiffness, thus impacting suction efficiency. Failures

occurred mostly when the gripper encountered irregular surfaces or obstructed ones, like

chicken wings.

### 2.14 Design and Development of Pick and Place Arm Robot

Author : Design and Development of Pick and Place Arm Robot

The paper presents the complete design, fabrication, and evaluation of a low-cost, electro-

pneumatically actuated pick-and-place robotic arm for industrial material handling. This study

seeks to enhance productivity of processes like machining, sheet-metal operations, and

assembly where manual handling is time-consuming and repetitive. This robot is specially designed to transfer lightweight objects between two stations, such as glass blanks, plastic caps,

or small sheet-metal parts, each weighing approximately 100 grams.

The design methodology undertaken by the authors is structured, starting with conceptual

layout sketches, followed by CAD modeling, and finally the development of the assembly. The

robotic system consists of a base frame, lead screw, rack-and-pinion rotation mechanism,

pneumatic cylinders, and vacuum suction grippers. The rotation of the arm is provided by

means of a rack actuated through a pneumatic cylinder, which allows for 180° clockwise and

counterclockwise motion in order to transfer objects between stations. Vacuum grippers are

preferred since they are suitable for flat and smooth surfaces and are very inexpensive.

The control architecture combines electrical and electro-pneumatic circuits, which are

developed and simulated using Festo Fluidsim to ensure coordinated actuation of the three

double-acting pneumatic cylinders responsible for gripping, releasing, and rotating. The robot

can operate in either manual or automatic modes, allowing flexibility during setup and testing.

Material selection and beam deflection calculations are performed so that the arm has sufficient

stiffness to limit its deformation under load within safe limits.

Experimental testing has demonstrated significant gains in performance. One full pick-and-

place cycle takes the system about 8 seconds, which translates into 900 objects per hour

transferred-nearly twice the throughput compared with manual handling. Automated operation

decreases human fatigue, minimizes errors, and reduces material-handling costs.

The authors conclude that the electro-pneumatic approach is a simple, reliable, and economic

solution for small-scale industrial automation. Future enhancements will include full

automation by the addition of sensors and advanced control for increased precision and

versatility.

### 2.15 A Review of Robotics and Autonomous Systems in the Food Industry:

From the Supply Chain Perspective

Author: Linh N.K. Duong, Mohammed Al-Fadhli, and Sandeep Jagtap

The paper by presents an extensive review of the role of RAS in improving productivity,

efficiency, and sustainability throughout the whole food supply chain. Unlike most earlier

works that focused primarily on the technological aspects of robotics, this paper adopts a

holistic supply chain perspective to explore how RAS affects every stage of the food system,

from farming and processing through distribution and logistics to waste management.

The authors performed a systematic review of 54 research papers from the period between the

years 2000 and 2020, adhering to a structured nine-step approach. Their thematic analysis

identified five main areas of foci, in which RAS contributes to transformative impacts: food

quality, food safety, waste reduction, efficiency of supply chains, and supply chain analyses.

Each of these themes illustrates how automation and digitalization can enhance control,

traceability, and sustainability within global food networks.

RAS, in its turn, allows improved monitoring and control of freshness and appearance of food

with the help of machine vision, sensors, and image processing. Multispectral imaging, IoT-

enabled monitoring, and cyber-physical systems provide real-time assessment capabilities for

parameters such as color, ripeness, and texture. Robotics improve food safety through

traceability systems like RFID and blockchain integrations, recording product origin,

temperature, and handling information for compliance with safety standards such as HACCP.

The paper throws light on IoT-based systems that track waste generation in real time, thus

helping manufacturers to identify inefficiencies in their production lines. For instance,

autonomous vehicles and drones can support crop inspection, delivery, and warehousing

operations, while intelligent algorithms optimize inventory and routes of transport. The study

identifies several key challenges to RAS adoption: data availability, cybersecurity risks, high

investment costs, and skill shortages in handling advanced technologies. It further emphasizes

that while robotics can significantly improve productivity and resilience, such wide-scale

implementation requires collaboration from industry, government, and academia.

### 2.16 Pick and Place Robotic Arm: A Review Paper

Author : Sharath Surati, Shaunak Hedaoo, Tushar Rotti, Vaibhav Ahuja, and Nishigandha Patel

The paper provides a comprehensive overview of design principles, operational mechanisms,

and technological advances in industrial pick-and-place robotic arms. By consolidating

findings from multiple research studies, it traces the evolution of robotic manipulators and

discusses how improvements in mechanical design, control strategies, and sensing technologies

strengthened their roles in modern automation. Robotic arms substantially enhance precision,

efficiency, and safety within an industrial environment and are especially very helpful around

hazardous areas like high-temperature zones, metal fabrication workshops, and assembly lines.

The paper defines a robotic arm as a programmable mechanical manipulator consisting of

linked joints that simulate the motion of the human arm. Different architectures of robots are

described: | Cartesian, | cylindrical, | spherical, | SCARA, | articulated, | parallel, | and

anthropomorphic. Configuration and industrial suitability are discussed for each type.

Cartesian manipulators are suitable for applications requiring precision in pick-and-place

operations; SCARA robots operate well in high-speed assembly; while articulated robotic arms

have multiple rotary joints and find extensive applications in welding, painting, handling, and

general automation tasks due to their flexibility and wide workspace coverage.

Controllers and sensors have a major emphasis in making the motion of the robot accurate,

adaptive, and intelligent. Microcontrollers like Arduino and single-board computers like

Raspberry Pi are also used to provide closed-loop control to execute trajectories smoothly and

adjust grip in real-time. Object detection systems based on computer vision are also reviewed,

with particular emphasis on the use of YOLOv3 for fast and accurate recognition and

localization of items to improve the reliability of automation. Other examples using color-

sorting robotic arms with photodiodes, wireless gesture-controlled arms with flex and gyro

sensors, and more advanced systems utilizing fuzzy logic or genetic algorithms to optimize

motion planning and reduce settling time.

### 2.17 A Methodology for the Design of 6D Robotic Arm

Author : Y Mona Younis, Eman Nasser, Amal Nasser

The present paper deals with the design, modeling, and validation of a 6-DOF robotic arm

manipulator using analytical inverse kinematics based on the Denavit–Hartenberg convention.

The objective is to enable the robotic arm to quickly achieve any desired position in space with

precision in its orientation, maintaining mechanical feasibility, structural strength, and

precision in motion control.

This methodology follows a well-structured three-stage process: design objectives, preliminary

mechanical design, and kinematic modeling with validation. The design objectives include the

development of a functional arm that can pick up and place objects, PID-based control for

positioning accuracy, and MATLAB-based GUI for intuitive user interaction. The robot's

mechanical parts are fabricated using aluminium 6061 because of its lightweight, formability,

and durability. CAD modeling is done in SolidWorks, and components are laser-cut and 3D-

printed before assembly.

The final design includes six joints, a maximum reach of 700 mm, and a payload capacity of 1

kg. Belt-and-pulley transmissions increase the torque of joints while reducing the motor speed.

Firstly, the kinematic analysis is done in a standard DH framework that defines link offsets, twists, lengths, and joint angles to derive the forward and inverse kinematic equations. A

complete DH parameter table and the transformation matrices are constructed to calculate the

position and orientation of the end-effector (Rxyz). The authors then derived the complete

analytical inverse kinematic solution for all six joints by equating the elements of

transformation matrices to ensure that the robot could reach any valid point inside the

workspace.

Validation is performed in the MATLAB Robotics Toolbox, where the correctness of the

derived joint values is checked by forward kinematic reconstruction and visual plot

simulations. The system is extended with a MATLAB GUI that allows for manual joint control,

Cartesian command mode, creation of trajectories, and replay of tasks.

The authors conclude that the proposed methodology successfully delivers a precise, efficient

6-DOF robotic arm capable of reliable pick-and-place operations, with accurate inverse

kinematics and user-friendly control architecture suitable for industrial and research

applications.

### 2.18 Safety-Critical Manipulation for Collision-Free Food Preparation

Author : Andrew Singletary, William Guffey, Tamas G. Molnar, Ryan Sinnet, Aaron D.

In this paper, a novel framework is introduced to ensure safety and efficiency for robotic motion

in performing food preparation tasks within dynamic environments. The work focuses on one

of the most pressing issues in robot cooking: how to guarantee collision-free manipulation

when robotic arms interact with various moving and deformable objects in real-time. With the

employment of Control Barrier Functions, the method dynamically updates existing motion

trajectories; robots can adapt to environmental changes without needing full re-planning. This

significantly improves the computational load while maintaining formal safety guarantees.

The paper begins by emphasizing that robotics integration is being increasingly implemented

in food service industries, including automated frying, dispensing, and kitchen operations.

These tasks require periodic reassessment of trajectories due to unstructured and usually

unpredictable variations, such as utensil shifts, object deformation, and worker interference.

Classic trajectory planners, such as CHOMP, TrajOpt, and OMPL, are computationally

cumbersome and often infeasible for real-time updates. The authors introduce a CBF-based

safety filtering framework that efficiently updates precomputed trajectories to ensure safety in

changing environments. It builds on providing formal, mathematical proof for safety by

extending guarantees from kinematic control to full dynamic behavior of robotic manipulators.

When environmental conditions change, the algorithm computes the safe velocity commands

through QP, minimally updating desired inputs to satisfy safety constraints.

The study has also embedded realistic signed distance functions to calculate the separation of

the robot and obstacles, with accurate computation of geometry-sensitive collision avoidance.

This methodology has been integrated into a full-scale food-handling manipulator in

collaboration with Miso Robotics, the creators of the "Flippy2" robotic cooking platform.

Experiments done under natural kitchen conditions showed that computation time and safety

performance significantly improved compared with other conventional re-planning systems.

Results proved the ability of the robot to dynamically cope with cooking environments that

change, such as the shifting of fry baskets or moving human operators, without negatively

affecting efficiency and safety.

### 2.19 Challenges and Opportunities in Robotic Food Handling

Author : Wang, Hirai, and Kawamura

The paper gives an in-depth review of the current challenges, research advances, and future

directions on food manipulation automation. Key issues have been framed within three realms:

robotic end-effector design, food recognition, and fundamental information about food

properties, and further advances in each realm have been explored along with the identification

of opportunities for future research. This review begins by explaining how automation at food

factories is now crucial for productivity, hygiene, and safety in the post-pandemic era. While

traditional robots are already used for repetitive operations such as packaging and palletizing,

many food-handling tasks—such as picking moist, deformable, or irregularly shaped items—

remain challenging. It has been pointed out that the key bottleneck to achieving full automation

is the lack of versatile, hygienic, and low-cost end-effectors.

For robotic end-effectors, the authors classify gripping methods based on the contact position:

top, side, bottom, or combinations thereof. The most common are suction-based grippers,

which are simple and fast but limited to dry, smooth surfaces. Alternatives such as Bernoulli,

Coanda, adhesive, freezing, and soft grippers have been developed to handle different food

textures. The paper notes that soft robotic technologies have made significant progress, with

commercial examples like Soft Robotics Inc.’s mGrip and Festo’s Fin Ray gripper effectively

handling fragile fruits and vegetables. However, these solutions still face issues of cost,

cleaning, and adaptability. In food recognition, the authors differentiate between 2D

recognition for objects on conveyors and 3D recognition for random bin-picking (RBP)

scenarios. While traditional 2D pattern matching is mature, RBP remains difficult due to overlapping and deformable objects. Advances in deep learning-based methods, such as Faster

R-CNN and YOLOv3, have improved recognition accuracy and pose estimation in

unstructured environments. These techniques are now being applied to non-rigid objects like

meat, vegetables, and cooked foods. The paper also stresses the lack of quantitative data on

food properties such as elasticity, viscosity, friction, and geometry, which are crucial for

developing accurate robotic models and grasping strategies. The authors advocate creating a

comprehensive food property database similar to the Yale-CMU-Berkeley dataset used in

general robotics, to standardize research and improve end-effector design.

### 2.20 An Automated Robotic Arm: A Machine Learning Approach

Author : Krishnaraj Rao N S,Avinash N J ,Ram Moorthy H

The paper presents the design and implementation of a machine learning-based, computer-

vision-guided automated robotic arm for performing pick-and-place operations. The main goal

of this study has been the integration of object detection, recognition, and motion control into

one system that could work autonomously with minimal human interference. Employing

machine learning, the robotic arm is allowed to identify objects by means of visual input, make

decisions on its movements according to the data learned, and manipulate the objects physically

in a highly efficient way.

The proposed system is implemented on a Raspberry Pi controller integrated with five servo

motors and a Raspberry Pi Camera Module (Raspicam). The arm is 3D printed using PLA

material, with joints actuated by MG996, MG995, and MG90S motors for five degrees of

freedom. A Python-based control program, running on the Raspbian OS, manages motor

actuation through GPIO pins and processes camera input for object detection with TensorFlow

and OpenCV libraries. The camera detects objects within its field of view, classifies them, and

sends the positional data to the controller. From the data provided, the Raspberry Pi calculates

the required rotations of the motors through inverse kinematics to reach, grasp, and move the

object. The software stack consists of TensorFlow for the machine learning-based object

detection part, OpenCV for image processing, and PuTTY along with VNC Viewer for remote

system access and visualization. The robotic arm is designed with an ultrasonic sensor to

calculate object distance by using the HC-SR04 and a barometric pressure sensor to verify if it

has successfully gripped the object using the BMP-180. It assures accurate pick-up operations.

The end effector-gripper-is designed to handle small and lightweight objects, while control

precision is achieved by calculating PWM duty cycle. Experimental results showed that the arm could identify, pick, and place objects autonomously with high accuracy. The

incorporation of computer vision and machine learning enhances adaptability immensely in

unstructured environments. Such a system, the authors conclude, has immense potential for

industrial and domestic automation, reducing human involvement while increasing reliability

and efficiency.

### 2.21 Intelligent Soft Robotic Grippers for Agricultural and Food Product

Handling: A Brief Review with a Focus on Design and Control

Author: Yuxuan Liu, Jixin Hou, Changying Li, and Xianqiao Wang

The paper offers an in-depth review of the design principles, material selection, and control

strategies that define modern soft robotic grippers developed for agricultural and food-handling

applications. It emphasizes the fact that traditional rigid robotic systems—while highly

effective in industrial manufacturing—are inherently unsuitable for fragile, irregular, and

deformable food products. Soft robotics, constructed from compliant materials like silicone,

elastomers, and hydrogels, is recognized as a transformative solution that can deliver gentle,

adaptive, and intelligent manipulation to meet the delicate requirements of agricultural produce

and processed foods. A key theme of the paper is the bio-inspired nature of soft grippers,

mimicking structures such as octopus tentacles, elephant trunks, and human hands. These

systems have shown outstanding flexibility and adaptability; for this reason, soft grippers are

able to distribute forces uniformly on the contact surfaces. This reduces problems of bruising,

tearing, and wastage associated with rigid grippers. Their inherent compliance makes them

ideal for grasping fruits and vegetables and other food items of different geometries, textures,

and stiffness, with improved efficiency in harvesting and higher product quality.

The authors classify soft actuators, the effective "muscles" of soft grippers, as fluidic,

mechanical, jamming-based, and hybrid. Pneumatic actuators, such as PneuNets, are the most

common due to their simplicity and low cost, demonstrating high adaptability and achieving

bending and grasping motions through the inflation of internal air chambers. Vacuum-based

actuators provide stronger, more uniform grasping, while fiber-reinforced soft actuators

increase load capacity by constraining unwanted deformation. Jamming-based actuators stiffen

granular or layered materials under vacuum, thus allowing tunable rigidity and universal

gripping. Tendon-driven systems achieve high precision by using the tension of cables and are

therefore suitable for delicate fruit-picking tasks. While substantial progress has been achieved, the paper points out remaining challenges with durability, control complexity, material

scalability, and environmental sensitivity.

### 2.22 Robotics and Machine Vision for Primary Food Manipulation and

Packaging

Author : Saigopal Vasudevan, Mohamed Lamine Mekhalfi, Carlos Blanes, Michela Lecca, Fabio Poiesi, Paul Ian Chippendale, Pablo Malvido Fresnillo, Wael M. Mohammed, and Jose
L. Martinez Lastra

The paper gives a critical technical review of robotics and machine vision technologies for the

automation of primary food processing, which involves all essential operations immediately

after harvest, including sorting, cleaning, grading, and packaging. The growing need for

automation is underlined by labor shortages, strict hygiene requirements, and increasing

production demands, especially in Europe, where 99% of the food industry consists of SMEs

that increasingly favor flexible, reconfigurable robotics over expensive, specialized machinery.

Automation of primary food handling is uniquely challenging because many food products

have high variability in shape, texture, and moisture content, and fragile items require very

careful grasping, cutting, or sorting action to avoid bruising or other damage. No single robotic

solution can handle these tasks, and each application requires customized end-effectors and

vision systems for different products. This review groups automation systems into two broad

components: sensing technologies (machine vision) and actuation systems (robotic

manipulators and end-effectors).

The paper reviews RGB imaging, multispectral, and hyperspectral sensing, and 3D imaging as

representative non-destructive and high-speed techniques for quality assessment in machine

vision. Such systems are capable of detecting bruises, estimating ripeness, assessing the quality

of meat, and finding contaminants. Artificial intelligence integrated with deep learning greatly

improves the accuracy in real time by allowing object recognition, detection of defects, and

classification of diseases. However, some of the areas that still remain challenging are

illumination control, reflective surfaces, and handling large datasets.

On the manipulation side, the authors review different robot configurations, such as SCARA,

delta, articulated, Cartesian, and collaborative robots. SCARA and delta are best suited for fast

pick-and-place operations, while the articulated and cobot systems have greater dexterity for

fragile or irregularly shaped products. It also highlights hygienic, food-grade design with easy

cleaning and resistance to environmental conditions.

### 2.23 Prospects of Robotics in Food Processing

Author : Y. B. Wakchaure, B. K. Patle, and Sachin Pawar

The paper reviews the evolution, applications, and future prospects of robotics in food

processing, showing how automation has transformed manufacturing, packaging, and

distribution to meet global challenges such as population growth, labor shortages, hygiene

concerns, and rising consumer expectations. Historically, the food sector has been slower to

adopt automation compared with other manufacturing sectors, but today it is identified as one

of the top four domains that can be most automated.

Drivers include a growing need for food safety, high-quality food, and mass production,

coupled with increased productivity and reduced human error. According to the paper, about

94% of packaging operations in the food industry are already roboticized, especially in areas

like palletizing, sorting, material transfer, and high-speed pick-and-place.

The review covers segments of the food industry like grains, sugar, dairy, beverages, meat,

seafood, bakery, fruits and vegetables, spices, frozen food, etc., showing how robotics has been

integrated at different stages of processing. This was appropriately represented with examples

such as RGB and NIR sensor optical sorting machines for grain defect detection, automated

vacuum systems for consistent sugar juice extraction, HPP in beverage preservation, and AMS

in dairy operations. Robots are increasingly performing delicate, specialized tasks such as meat

deboning, cake decoration, and cheese cutting with much higher precision and hygiene than

manual labor.

All these developments are situated within the broad frameworks of Industry 4.0 and Industry

5.0, with cyber-physical systems, IoT, AI, cloud computing, and machine learning playing the

central role. Such technologies enable better traceability, real-time monitoring, predictive

maintenance, and autonomous decision-making, while transforming workforce roles by

shifting workers away from repetitive labor to supervisory and technical ones.

The authors conclude by emphasizing that robotics has become indispensable in modern food

manufacturing. It improves hygiene, safety, efficiency, and product quality in all stages: from

raw material handling to end-stage packaging. The authors look ahead and envision a future

dominated by intelligent robots, AI-driven inspection, and adaptive soft grippers, which

altogether will drive fully automated, sustainable, and consumer-responsive food processing

environments.

### 2.24 Robotics Revolution: Transforming the Food Industry Through

Automation and Innovation

Author : Dr. G. Nedumaran and M. Madhuritha

The paper explores how robotics, artificial intelligence, and automation technologies are

redefining the food industry worldwide, from farm to fork. While the food sector has been

slower than others to embrace automation, pressures such as a lack of labor, high levels of

hygiene required, and a growing demand for safe and high-quality food have led in recent years

to a faster pace in the use of intelligent robotic systems. All these pressures were further

increased by the COVID-19 pandemic, which showed weaknesses in food production and

staffing, and the rapid integration of robotics into manufacturing, packaging, and delivery of

foodstuffs is the result.

The authors identify five major domains where robotics is already making a big difference:

agriculture, manufacturing, packaging, cooking, and delivery. In agriculture, autonomous

robots and drones monitor crops, allow for selectivity in harvests, and supervise livestock,

hence enhancing precision and reducing the need for seasonal labor. For instance, fruit-

harvesting robots from T&G Global improve picking efficiency while reducing product

damage. Food manufacturing involves the use of robots for performing repetitive tasks that are

hazardous to human life, such as sorting, cutting, and meat processing. Companies like Tyson

Foods employ robotic systems to separate meat and package it, improving hygiene and

increasing throughput.

In the process of packaging, robotic equipment repeatedly assembles, labels, and seals products

while supporting eco-sustainability through optimized material use and integrating

biodegradable packaging. Culinary robotics is another area worth mentioning, as systems like

"Flippy", developed by CaliBurger, are able to cook foods like fries and hamburgers with great

precision and consistency, using considerably less labor. Further advancing last-mile logistics

come autonomous delivery robots and drones employed by companies like Kroger and Starship

Technologies, enabling safe, contactless delivery.

The authors conclude that robotics will dominate the future of food processing, packaging, and

distribution. The food industry is moving toward safer, faster, and more sustainable automated

ecosystems through combinations of AI, smart sensing, and collaborative human–robot

systems.

### 2.25 Robotic Handling of Compliant Food Objects by Robust Learning

from Demonstration

Author : Ekrem Misimi, Alexander Olofsson, Aleksander Eilertsen, Elling Ruud Oye, John

Reidar Mathiassen

The paper proposes a robust LfD framework that enables teaching robots to handle fragile and

deformable food materials like fish, meat, and vegetables-materials inherently exhibiting

variable size, shape, and mechanical texture. Traditional robot grasping systems are not

satisfactory for such manipulations, as they rely mainly on rigid-body assumptions and pure

vision-based approaches. This paper presents a multi-modal LfD approach that fuses RGB-D

visual data with tactile feedback in order to estimate optimal grasp pose, finger configuration,

and gripping force, while automatically filtering inconsistent human demonstrations.

In this paper, we use a 6-DOF Denso VS087 robot arm, a ReFlex TakkTile multi-fingered

gripper, and a Kinect v2 RGB-D camera. During teleoperation, a human teacher demonstrates

grasping motions using Sixense STEM controllers, recording data about gripper position and

orientation, as well as tactile pressure and RGB-D images. These demonstrations are used as

training examples for the robot. We collected a dataset of 525 demonstrations using lettuce

because of its high compliance and variability, and data augmentation was performed to

improve generalization.

A key contribution of this work involves the automatic rejection of inconsistent

demonstrations. Rather than manually discarding poor data, the authors use a one-class Support

Vector Machine to discover outliers in the state-action space and retain only those

demonstrations which are consistent with the intended policy. Subsequent ε-insensitive

Support Vector Regression learns a mapping between visual-tactile features and grasping

actions. This combination yields a robust policy which generalizes well even under

demonstration variability.

Experimental validation reveals that 497 of 525 demonstrations were consistent, and after

filtering, the robot reached an average grasp success rate of 75% on unseen lettuce samples.

The system demonstrated stable grasping by adjusting its finger pressure dynamically

according to tactile feedback, although occasional failures were caused by incorrect gripper

orientation or uneven object surfaces.

### 2.26 Robotic Grippers in Food Industry

Author: Hamid Abdullayev and Elnur Huseynzade

It provides an overview of technological advances and their limitations, as well as new

emerging trends concerning robotic gripping systems in the food industry. The authors have

outlined the challenges in manipulating soft, weak, and unstructured materials like fruits,

vegetables, and raw meat using conventional industrial grippers, which cannot accommodate

delicate textures, irregular geometries, or moisture-rich surfaces. Considering that food

products are so easily damaged by excessive force, slipping, or inappropriate contact, the

authors support the need for novel, hygienic, and adaptable gripping technologies capable of

preserving the integrity and safety of such products. Food processing presents unique

difficulties not encountered in standard manufacturing, including softness, irregular shapes and

surfaces, contamination risks, and complex grip physics.

These challenges are grouped by the authors into five essential domains: soft material requiring

gentle force control, uneven surfaces decreasing suction stability, irregular forms complicating

grasp planning, hygiene demands compelling food-grade materials, and the constraints of

physics imposed on force distribution during gripping.

The paper reviews various gripping mechanisms: pinch, penetration, suction, and freezing-

based "surface effect" grippers. Pinch grippers use friction but may crush fragile objects;

penetrating grippers insert pins that interlock with the surface and cannot be used with edible

products; suction grippers require a smooth, dry surface yet do not perform well on wet foods;

and freezing-based systems use a thin layer of ice to attach to high-moisture objects like meat.

The authors review two-finger, multi-finger, and servo-driven mechanisms that apply force

dynamically, as well as anthropomorphic designs modeled on human hands, though these are

generally expensive and mechanically complex.

This review concludes that while development has indeed been significant, soft, hygienic, and

sensor-integrated grippers remain an area of active development. Future advancements of the

technology will depend on soft robotics, advanced sensing, and machine-learning-based

control to realize gentle, reliable, and contamination-free food automation.

### 2.27 Automation and Optimization of Food Process Using CNN and Six-Axis

Robotic Arm

Author : Youngjin Kim and Sangoh Kim

This paper proposes the FPRIS, which is a totally automated AI-driven framework

incorporating robotics, computer vision, and smart sensing for coffee roasting process

optimization. By enhancing the precision, consistency, and safety of operations, FPRIS

embodies a specially designed 3D-printed six-axis robotic arm, multisensory feedback, and

CNN monitoring and controlling real-time roasting.

As the primary actuator in the system, the six-axis robotic arm is fabricated through 3D

printing. This will dynamically observe changes in the roasting chamber and make parameter

adjustments as required. The system is integrated with RGB cameras, thermocouples, and MQ-

3/MQ-7 gas sensors to continue gathering data on the color of the beans, temperature, and

generated gases throughout the operation. These multimodal inputs are processed by the

BeanFinder CNN (BFCNN), a custom deep-learning model that was trained to classify coffee

beans and estimate their Degree of Roasting (DoR) from over 11,000 images. The CNN

segregates beans from empty and noisy backgrounds and achieved a high accuracy of

classification of about 97.59%, allowing reliable identification of roast levels from light to

dark.

FPRIS independently controls roasting conditions such as gas intensity and roasting time using

the predictions from CNN and through robotic actuation. To investigate the validity of the

system, the authors conducted tests on PCS and VCS, considering color (L*, a*, b*), gas index,

weight loss, and pixel brightness. Experimental results demonstrated a good agreement

between PCS and VCS, validating that with an increase in the darkness degree of roast, gas

emissions and weight losses were significantly higher, while decreases were observed in the

grayscale and color metrics as expected from the roasting behavior.

The study concludes that FPRIS achieves roasting precision comparable to expert human

operators while improving safety by monitoring CO levels. Beyond coffee, the authors propose

extending the system to other thermal food processes—such as baking, drying, and frying—

positioning FPRIS as a scalable AI-robotics platform for next-generation Food Processing 4.0.

### 2.28 Design and Control of Soft-Rigid Grippers for Food Handling

Author : Valerio Bo, Leonardo Franco, Enrico Turco, Maria Pozzi, Monica Malvezzi, Domenico Prattichizzo, and Gionata Salvietti

The paper presents the design, control methodology, and experimental evaluation of a novel

soft–rigid, tendon-driven robotic gripper—the Double-Scoop Gripper, DSG—engineered

specifically for food handling in confined and cluttered environments. The gripper is intended

for delicate pick-and-place operations involving fragile, easily deformed, or irregularly shaped

food items stored in narrow trays and containers. The combination of structural rigidity with

mechanical compliance allows the DSG to perform gentle manipulation while supporting

efficient motion planning required in real-world food-handling tasks.

It has two scoop-shaped fingers that can flex to form a single plate. Each finger includes a rigid

internal plate surrounded by a flexible TPU border that enables the gripper to slide underneath

soft food items and lift them without applying damaging pressure. Actuation is through a

tendon-driven mechanism-providing precise control along with reduced friction and lower

mechanical complexity. Made of ABS-like resin and TPU (Shore 85A), the DSG is lightweight

and strong, with an onboard camera supporting vision-based feedback.

One of the main contributions to this work is a data-driven approach for designing a gripper,

incorporating past grasping experience into the geometry of the gripper. Through simulation

and topology optimization, the scoop structure is refined for stability while minimizing material

usage and adapting to the environmental constraints. The authors also developed specialized

control strategies, leveraging container walls and surrounding structures for aiding grasp and

release actions. Four grasping strategies and three placing strategies are defined based on object

position, height variation, and container geometry.

Extensive experiments performed using a UR5 robotic arm across different food items such as

meatballs, sausages, cookies, carrots, and zucchini demonstrate the grasp success rate at 88.6%

and release success rate at 97%. The DSG effectively handled single and multiple items without

damage, even in restricted areas.

### 2.29 Review of Robotic Grippers for High-Speed Handling of Fragile Foods

Author : Yang Zhang and Zhongkui Wan

It provides an in-depth survey of the recent advancements, challenges, and emerging

opportunities in developing soft robotic grippers that can perform high-speed and damage-free

handling of fragile foods such as tofu, oysters, and pudding. While industrial robots have shown outstanding performance in manufacturing industries, their applications in food processing are

still quite limited owing to the delicate, deformable, and irregular nature of food items. The

paper identifies two key issues: food fragility and high-speed inertial effects. Foods with

extremely low Young’s modulus values-for example, tofu at 10–13 kPa and bread at 8–18 kPa-

exhibit deformed shapes under very minimal pressure. However, in industrial applications

where transferring 60–74 oyster pieces per minute is needed, increased mechanical stresses

associated with fast operations develop. Most robotic grippers currently lack the adaptability

and fine force regulation that can ensure safe handling of those materials at such high speeds.

To address these, the authors classify state-of-the-art solutions into three domains: damage-

free design, variable-property actuators, and cost-efficient optimization techniques. The

strategies for damage-free design involve soft–rigid coupling structures that are bioinspired

from human fingers, thus providing both stability and gentle contact. Form-closure grippers

increase the contact area to decrease localized pressure, thus offering safety for fragile foods.

Variable-property actuators could be in the form of jamming mechanisms, magnetorheological

fluids, or liquid metal alloys, while enabling the dynamic adjustment of stiffness, thereby

letting grippers change properties to cope with different food properties. However, the review

remarked that the current force feedback methods are too slow for real-time, high-speed

manipulation.

The paper identifies finite element analysis, topology optimization, and data-driven simulations

as tools that support design refinement without extensive physical testing. As for successful

industrial implementations, the commercially available soft grippers include Soft Robotics'

mGrip, Piab's soft hand, and Nitta's Softmatics.

### 2.30 Design and Field Evaluation of an End Effector for Robotic

Strawberry Harvesting

Author : Ezekyel Ochoa and Changki Mo

This paper describes the design, simulation, and field validation of a pneumatically actuated

end effector integrated with a Delta X parallel robot for automated strawberry harvesting. The

study addresses severe labor shortages in the U.S. strawberry industry by proposing an

affordable, modular, and high-speed robotic system that is able to operate in open-field

environments-an area where current commercial harvesters struggle due to variable terrain and

dense foliage.

Strawberry picking is still very labor-intensive because the fruit is fragile and has to be picked

gently to avoid getting bruised. Systems already in place, like Organifarms' BERRY and

Dogtooth Technologies harvesters, although promising, are very expensive and generally

bound to controlled greenhouse or tabletop production. The proposed solution targets open-

field farms, where strawberries grow closer to the ground, are more variable in their

environment, and therefore call for a more flexible robotic design.

It utilizes a commercial Delta X parallel robot due to its high precision, rigidity, fast movement,

and affordability. A lightweight (0.271 kg) 3D-printed PLA end effector was designed with a

pneumatic blade mechanism that can cut, pinch, and hold the strawberry stem simultaneously.

At an operational pressure of 206.8 kPa (30 psi), the mechanism acts in real time with respect

to any change in airflow and thus provides speed during harvesting while maintaining the

payload limit of the robot at 0.5 kg. The end effector design is modularized to facilitate faster

replacement and modifications, resulting in further reduced operation costs.

Workspace analysis done in MATLAB and SolidWorks showed that the motion range of the

robot effectively covers standard two-plant-per-row configurations of a field. Field validation

at Farias Farms showed high performance, with 94.74% success in simulations and 100%

success during real harvesting, even under dense late-season foliage. The system was able to

harvest strawberries at 2.8–3.8 seconds per fruit, outperforming other systems such as Rubion

at 4 seconds and Dogtooth’s dual-arm harvester at about 25% of human speed.

## CHAPTER 3

## PROBLEM STATEMENT

The modern food industry faces tremendous pressure to maintain high standards related to

hygiene, speed, and accuracy in handling a large and fast-growing volume of food orders.

Conventional food handling methods involve higher contamination risks due to human contact,

inconsistent handling quality, and a slower speed of processing, with heavy dependence on

labour. These issues become even more crucial in Quick Service Restaurants, cloud kitchens,

and big food outlets where hundreds of orders must be prepared and dispatched within very

short time frames. In these high-demand environments, manual systems often fail to offer

uniform cleanliness, timely delivery, and order sorting accuracy.

The limitation of conventional food handling systems mainly points to the absence of

automation, especially in the identification and routing of food packets. Lack of an automatic

QR code or barcode reader mechanism on the food packages might result in errors, such as

wrong delivery, misplaced orders, and delay. These inefficiencies weaken the dependability of

the operations while growing customer dissatisfaction and adding extra workloads on staff.

Further, repetitive manual handling results in fatigue, which again affects accuracy and

consistency.

These challenges call for an automated solution that can safely, accurately, and continuously

execute food handling tasks. A Food Handling Robotic Arm offers an effective solution where

it reduces human interaction, hence promoting hygiene and reducing contamination risks.

Using QR or barcode scanning, the integrated system ensures correct identification of each

food item within a pack and delivery to a destination using precise robotic pick-and-place

operations. Such an automated approach enhances overall efficiency, improves order accuracy,

reduces dependency on labour, and supports reliable, high-speed food-handling operations

suitable for modern food service environments.

## CHAPTER 4

## OBJECTIVES

The objectives of the Food Handling Robotic Arm include solving some of the major

challenges in modern food service systems: hygiene, accuracy, and speed. Manual food

handling increases the risk of contamination and operation errors, especially in high-demand

settings. With the application of automation through the conveyor-based transport, order

identification with the use of labels, and robotic pick-and-place operations, the system reduces

human contact for accurate order delivery and provides fast, consistent, and hygienic food

handling.

- To reduce human contact with food, minimizing contamination risks and improving

hygiene in the food-handling process.

- To enable customers to place food orders through an application, where all required inputs

are provided and a QR code is automatically generated for each order, ensuring a seamless

digital ordering experience.

- To use a conveyor belt system to transport food items from the kitchen to the serving

counter, enabling smooth, continuous, and reliable movement of dishes without manual

intervention.

- To recognize orders using labels and QR codes generated at the ordering station and

scanned using a webcam, ensuring accurate identification and delivery of dishes.

- To automate the picking, placing, and handover of food items using a robotic arm for faster

and more consistent service.

## CHAPTER 5

## DESIGN & DEVELOPMENT

The Fig 5.1 illustrates the hardware control architecture of the food handling robotic arm

system. A webcam mounted above the conveyor scans the QR code on food packets and sends

the decoded data to the Arduino Uno through USB serial communication. The Arduino,

powered by 5 V from the laptop USB, acts as the main control unit and processes the received

data to generate appropriate control signals.

A PCA9685 16-channel PWM driver, powered by an external 5 V adapter, is interfaced with

the Arduino to provide accurate and stable PWM signals for controlling multiple servo motors

of the robotic arm and gripper. This offloads PWM generation from the Arduino and ensures

smooth motion. The Arduino also controls the 12 V DC motor–driven conveyor system,

enabling synchronized packet transport and pickup. Overall, the diagram represents a clean

separation of logic power and actuation power, ensuring reliable and safe operation of the

robotic food handling system.

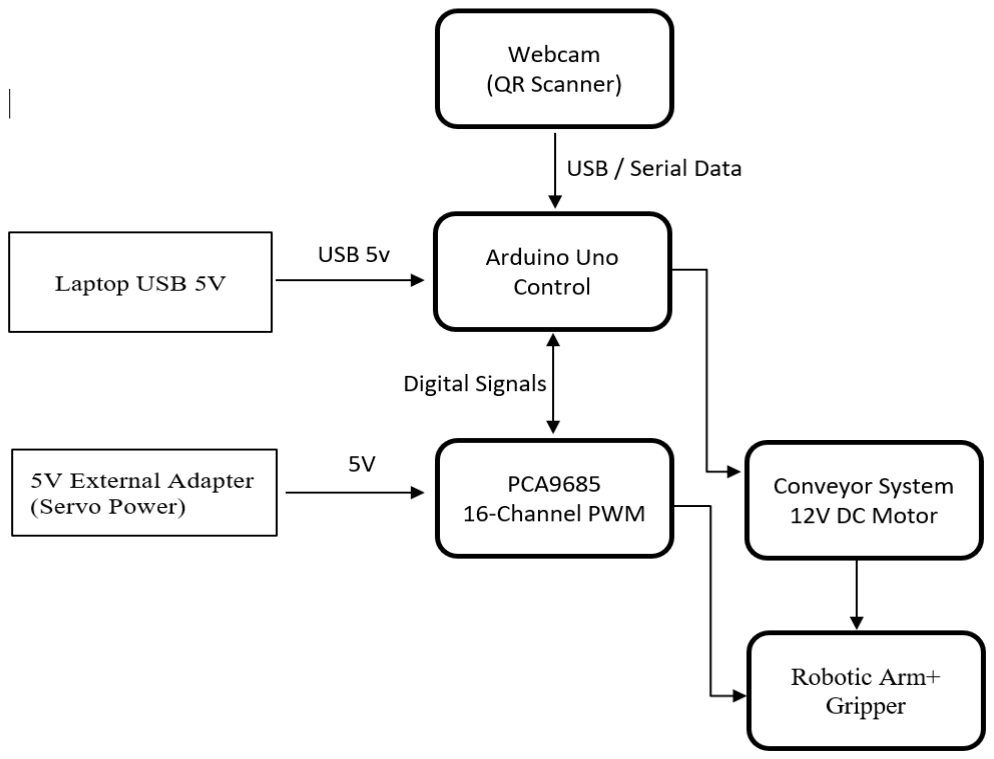
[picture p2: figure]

Fig 5.1 : Block Diagram of Hardware control architecture

### 5.1 Overview

The methodology defines a combined approach for perception, identification, motion planning,

and manipulation of food automatically. The structure of the system is modular in nature, with

three subsystems cooperating: perception, control, and robotic actuation, each designed to

comply with the hygiene, accuracy, and speed as set by the project scope.

The perception subsystem should ideally perform real-time detection and identification of food

packets that are in motion on a conveyor. Herein, an embedded camera captures frames that

undergo pre-processing, QR/barcode localization, and decoding. Output parameters include

customer ID, bin assignment, and pickup coordinates.

The control subsystem converts decoded data into executable motion trajectories. Inverse

kinematics and state-based logic are executed on a microcontroller to create joint commands

for the manipulator. The system operates through an eight-state finite-state machine: Idle,

Detect, Decode, Localize, Approach, Grip, Transport, and Place. Trajectory generation

leverages precomputation of keyframes to move at high speeds and invokes real-time inverse

kinematics to accommodate arbitrary positions of food items. Safety constraints imposed on

joint limits, collision avoidance, and gripper-force bounds accommodate packaged foods.

The actuation subsystem comprises a multi-DOF robotic arm integrated with a compliant food-

safe soft gripper. CAD-based simulations support the validation of reachability, constraints on

payload, and workspace coverage. The employed low-pressure, high-friction contact model

within the soft gripper avoids slippage and deformation of food packets.

The total workflow thus integrates sensing, decoding, trajectory planning, gripping,

transportation, and placing into one continuous automation loop. System validation entails

accuracy tests, cycle time measurement, evaluation of the sorting success rate, and reliability

in the case of repeated operation. In this way, the methodology ensures repeatable, hygienic,

and identity-driven food handling consistent with modern automated kitchen and food

distribution environments.

### 5.2 System Design & Mechanical Design

The system design of the food handling robotic arm integrates a web-based ordering system,

QR code identification, conveyor mechanism, and robotic arm control into a single automated

workflow. The control unit processes QR data from a webcam, computes pickup coordinates,

and synchronizes conveyor and arm operations to ensure accurate and hygienic food handling.

### 5.2.1 System Design

The system was designed with a closed-loop automation cycle of detection, identification,

manipulation, and placement. For modularity, reliability, and ease of maintenance, the design

of the system follows a hierarchical architecture that includes:

1. Perception Unit: The Perception Unit is the front-end interface between the environment

and the robotic system. The unit captures visual data through an integrated webcam positioned

at the scanning station. When a food packet is placed on the conveyor, an infrared sensor detects

presence, enabling selective frame capture rather than continuous processing. The captured

frame undergoes QR-code detection and decoding.

The code contains a unique order number generated previously from the website used by the

customer for order placement. Once decoded, the Perception Unit sends the order number and

its detected spatial location in real time to the Processing and Control Unit.

2. Processing & Control Unit: The Processing and Control Unit interprets data and formulates

trajectories of motion. It translates decoded information to calculate the pickup coordinates

relative to the robotic workspace. A predefined calibration relationship converts image

coordinates into reference positions accessible by the robotic arm. The system employs inverse

kinematic computation to convert final positions of pickup and placement into corresponding

actuation angles at the joint level. The decisions on movement are carried out through a finite-

state logic that transitions sequentially through the standard states: Detect, Decode, Approach,

Grip, Transport, Place, and Reset-to-Home. The Arduino Uno is used as the central processing

controller. However, the computational overhead due to multi-joint actuations is minimized by

transferring PWM generation duties to the PCA9685 servo driver.

### 3. Robotic Manipulation Unit: A 6-DOF articulated arm comprises a mechanical two-finger

gripper. Each joint executes the motion profiles generated from kinematic computation. The

arm picks up the packet at the conveyor exit region, lifts with programmed vertical and

translational motions, and places it at the delivery area. There is no manual transfer since the

execution of the motion pipeline happens without external intervention.

### 4. Conveyor & Delivery Unit: The Conveyor and Delivery Unit ensures steady, continued

motion of packets into the scan and pick-up area. The conveyor itself establishes a reference

boundary of the workspace, providing well-defined regions of packet pickup. The delivery area

is fixed, providing a reliable release position that is easy for the customer to see.

### 5.2.2 Mechanical Design

The robotic arm was designed to be a 6-DOF articulated manipulator that has fine control in

orientation and positioning. The joints were allocated torque-heavy MG995 servos at the base,

shoulder, elbow, and wrist-pitch, while lightweight SG90 servos were used for wrist rotation

and the gripper. This hybrid actuator strategy allowed a balancing of cost, power consumption,

and weight.

The mechanical design process followed an iterative workflow that combined CAD modeling,

kinematic analysis, and motion simulation. In the CAD environment, Fusion 360 provided a

parametric setup where joint lengths, link shapes, and servo placements could be adjusted while

maintaining overall mass distribution and balance.

Key Mechanical Design Steps:

### 1. Base Joint Optimization

The base joint required the highest torque due to long lever arms and full-arm rotation. MG995

was picked because of its high stall torque. The base mount was designed with a large stable

footprint to minimize vibration and improve positional accuracy.

### 2. Shoulder & Elbow Joint Geometry

The load is concentrated on the shoulder and elbow. In order to minimize inertia without losing

stiffness, a lightweight link geometry was designed with hollow profiles. Stress due to bending

was analyzed by FEA simulations to ensure that the arm would be able to lift packets without

any structural deformation.

### 3. Wrist Assembly

The wrist had two joints: pitch (MG995) and rotation (SG90). Here, compactness and low mass

were prioritized to reduce the load on the upstream joints. The wrist bracket was designed to

integrate cable routing for cleanliness.

### 4. Soft gripper development

Compliance in the gripper was essential for not tearing or deforming delicate food packaging.

Therefore, a TPU/silicone-based structure of a gripper was chosen. The design simulated

human-finger curvature and patterns of pinch-grasp for improved adaptability.
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

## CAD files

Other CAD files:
Food_Handling_Roboticarm_Design.f3d

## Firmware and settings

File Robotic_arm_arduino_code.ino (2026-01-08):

// Serial-controlled 5-DOF Robotic Arm + Gripper
// Wrist Pitch removed. Preset positions added.

#include <Servo.h>

// Servo pins
const int PIN_J1 = 3;   // Base
const int PIN_J2 = 5;   // Shoulder
const int PIN_J3 = 6;   // Elbow
const int PIN_J5 = 10;  // Wrist Roll
const int PIN_J6 = 11;  // Wrist Rotate
const int PIN_G  = 12;  // Gripper

// Angle limits
const int J1_MIN=0,  J1_MAX=180;
const int J2_MIN=0,  J2_MAX=180;
const int J3_MIN=0,  J3_MAX=180;
const int J5_MIN=0,  J5_MAX=180;
const int J6_MIN=0,  J6_MAX=180;
const int G_MIN =0,  G_MAX =90;

// Smooth movement speed
const int MOVE_STEP_DELAY_MS = 8;

// Delay between each servo motion
const int SERVO_DELAY_MS = 150;

// Servo objects
Servo s1,s2,s3,s5,s6,sg;

// ---------------------- PRESET POSITIONS ----------------------
// {J1, J2, J3, J5, J6, G}

int PRESET_HOME[6] =  {90, 60, 120, 80, 0, 45};

int PRESET_P1[6]   = {90, 60, 90, 40, 0, 45};
int PRESET_P2[6]   = {180, 60, 90, 40, 0, 45};
int PRESET_P3[6]   = {180, 60, 105, 60, 0, 60};

int PRESET_PP1[6] = {180, 60, 105, 60, 0, 23};

int PRESET_P4[6]   = {180, 60, 90, 80, 0, 25};
int PRESET_P5[6]   = {45, 60, 110, 80, 0, 25};
int PRESET_P6[6]   = {45, 60, 120, 80, 0, 50};

int PRESET_PLACE[6] = {45, 60, 100, 40, 0, 50};

int PRESET_P7[6]   = {45, 60, 100, 80, 0, 50};


// ------------ Clamp helper -------------
int clampInt(int v,int lo,int hi){
  if(v<lo) return lo;
  if(v>hi) return hi;
  return v;
}

// -------- Smooth servo motion ----------
void smoothWrite(Servo &s, int target){
  int curr = s.read();
  if(curr == target) return;

  if(curr < target){
    for(int a = curr; a <= target; a++){
      s.write(a);
      delay(MOVE_STEP_DELAY_MS);
    }
  } else {
    for(int a = curr; a >= target; a--){
      s.write(a);
      delay(MOVE_STEP_DELAY_MS);
    }
  }
}

// ------------ Move all servos ----------
void moveToAngles(int j1,int j2,int j3,int j5,int j6,int g){

  smoothWrite(s1, clampInt(j1,J1_MIN,J1_MAX));
  delay(SERVO_DELAY_MS);

  smoothWrite(s2, clampInt(j2,J2_MIN,J2_MAX));
  delay(SERVO_DELAY_MS);

  smoothWrite(s3, clampInt(j3,J3_MIN,J3_MAX));
  delay(SERVO_DELAY_MS);

  smoothWrite(s5, clampInt(j5,J5_MIN,J5_MAX));
  delay(SERVO_DELAY_MS);

  smoothWrite(s6, clampInt(j6,J6_MIN,J6_MAX));
  delay(SERVO_DELAY_MS);

  smoothWrite(sg, clampInt(g ,G_MIN ,G_MAX ));
}

// ------------ Move preset --------------
void movePreset(int preset[6]){
  moveToAngles(preset[0],preset[1],preset[2],
               preset[3],preset[4],preset[5]);
}

// ------------- Serial command handler --------------
void handleLine(String raw){
  raw.trim();
  if(raw.length()==0) return;

  String up = raw;  
  up.toUpperCase();

  // ----------- PRESET COMMANDS ----------
  if(up=="HOME"){ movePreset(PRESET_HOME); return; }
  if(up=="P1"){ movePreset(PRESET_P1); return; }
  if(up=="P2"){ movePreset(PRESET_P2); return; }
  if(up=="P3"){ movePreset(PRESET_P3); return; }
  if(up=="PP1"){ movePreset(PRESET_PP1); return; }
  if(up=="P4"){ movePreset(PRESET_P4); return; }
  if(up=="P5"){ movePreset(PRESET_P5); return; }
  if(up=="P6"){ movePreset(PRESET_P6); return; }
  if(up=="PLACE"){ movePreset(PRESET_PLACE); return; }
  if(up=="P7"){ movePreset(PRESET_P7); return; }

  // ---------- HELP ----------
  if(up=="HELP"){
    Serial.println(F("Commands:"));
    Serial.println(F("  J1 J2 J3 J5 J6 G"));
    Serial.println(F("  Named: J1:90 J3:120 G:20"));
    Serial.println(F("Preset commands:"));
    Serial.println(F("  HOME, P1, P2, P3, PICK, P4, P5, P6, PLACE, P7"));
    return;
  }

  // Replace separators with spaces
  for(unsigned int i=0;i<raw.length();i++){
    char c = raw[i];
    if(c==':'||c==','||c=='=') raw[i]=' ';
  }

  // Token parsing
  char buf[150];
  raw.toCharArray(buf,sizeof(buf));
  char *tok = strtok(buf," \t");

  int nums[6];
  int n_nums = 0;

  bool sp[6]={0};
  int val[6]={0};

  while(tok){
    if(tok[0] != '\0'){

      if(isalpha((unsigned char)tok[0])){
        String T = String(tok);
        T.toUpperCase();

        char key = toupper(tok[0]);
        char *p = tok+1;

        while(*p && !((*p>='0'&&*p<='9')||*p=='-'||*p=='.')) p++;

        int v = (int)round(atof(p));

        int idx=-1;

        if(key=='J' && isdigit(tok[1])){
          int j = tok[1]-'0';
          if(j==1) idx=0;
          else if(j==2) idx=1;
          else if(j==3) idx=2;
          else if(j==5) idx=3;
          else if(j==6) idx=4;
        }
        else if(T.startsWith("G")) idx=5;

        if(idx>=0 && idx<6){
          sp[idx] = true;
          val[idx] = v;
        }
      }
      else {
        if(n_nums<6){
          nums[n_nums++] = (int)round(atof(tok));
        }
      }
    }
    tok = strtok(NULL," \t");
  }

  int currVals[6] = {
    s1.read(), s2.read(), s3.read(),
    s5.read(), s6.read(), sg.read()
  };

  int pos=0;
  for(int i=0;i<6;i++){
    if(sp[i]) currVals[i]=val[i];
    else if(pos<n_nums) currVals[i]=nums[pos++];
  }

  moveToAngles(currVals[0],currVals[1],currVals[2],
               currVals[3],currVals[4],currVals[5]);

  Serial.println(F("Done."));
}


// ------------------- MAIN LOOP --------------------
void setupServos(){
  s1.attach(PIN_J1);
  s2.attach(PIN_J2);
  s3.attach(PIN_J3);
  s5.attach(PIN_J5);
  s6.attach(PIN_J6);
  sg.attach(PIN_G);
}

void setup(){
  Serial.begin(115200);
  setupServos();
  delay(500);

  Serial.println(F("5-DOF Arm Ready. Type 'help'."));
}

void loop(){
  static String line = "";
  while(Serial.available()){
    char c = (char)Serial.read();
    if(c=='\r') continue;

    if(c=='\n'){
      handleLine(line);
      line="";
    } else {
      line += c;
      if(line.length()>200){
        line = line.substring(line.length()-200);
      }
    }
  }
}
